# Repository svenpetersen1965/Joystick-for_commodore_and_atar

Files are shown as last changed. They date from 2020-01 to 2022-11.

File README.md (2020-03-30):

# Joystick-for_commodore_and_atar
This is a joystick for Commodore C64 etc.

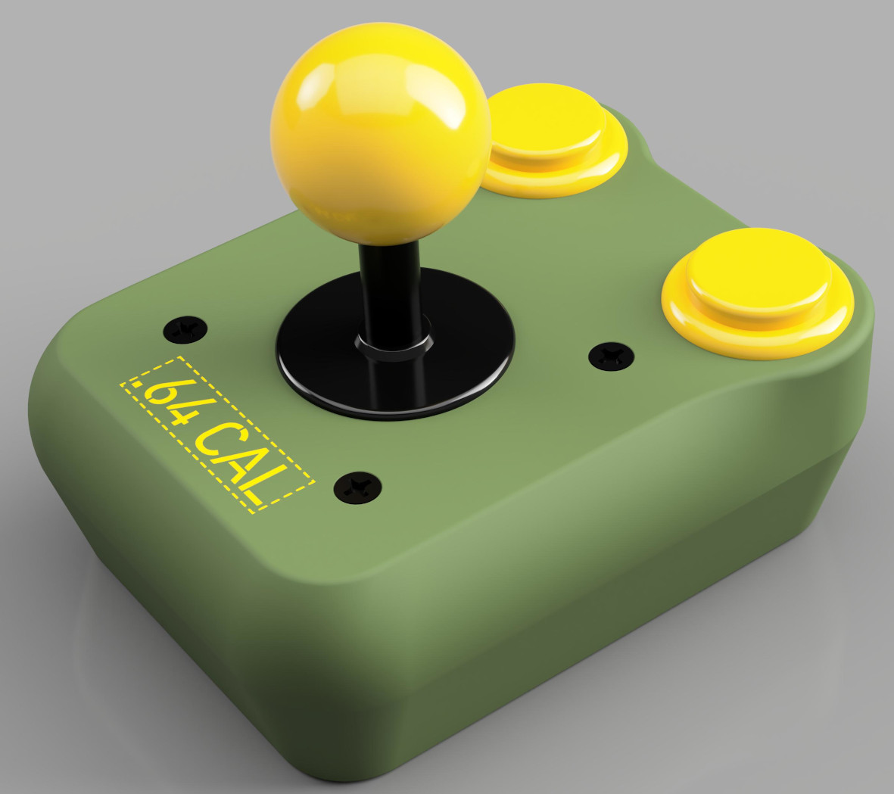
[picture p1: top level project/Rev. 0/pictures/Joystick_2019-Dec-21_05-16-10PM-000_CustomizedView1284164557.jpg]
Joystick


The Design is based on the widely available ZIPPYY joystick, which is of a  great quality.

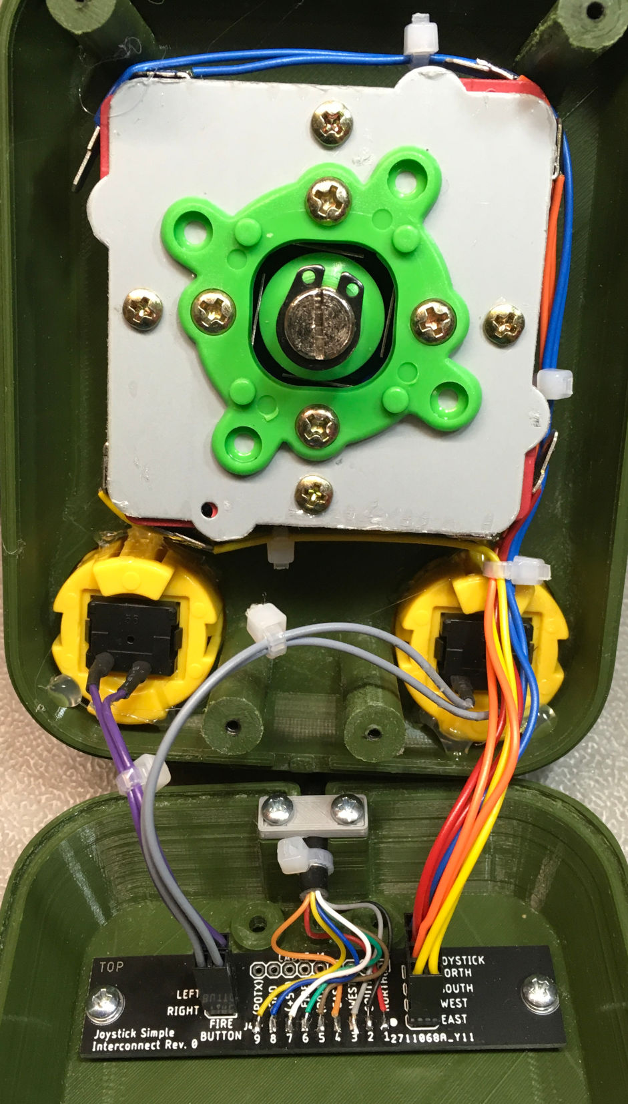
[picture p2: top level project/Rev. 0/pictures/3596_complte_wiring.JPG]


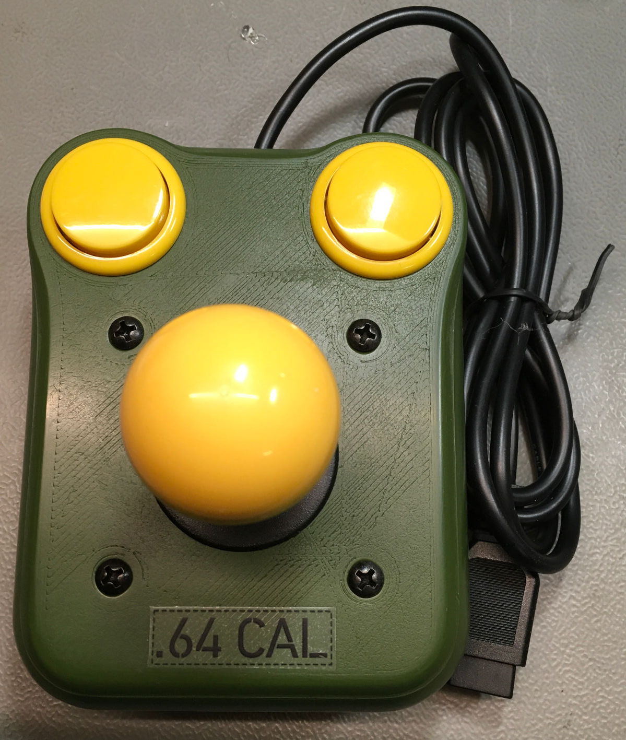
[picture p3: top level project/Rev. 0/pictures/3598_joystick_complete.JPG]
Joystick


There are now three alternative top shells:

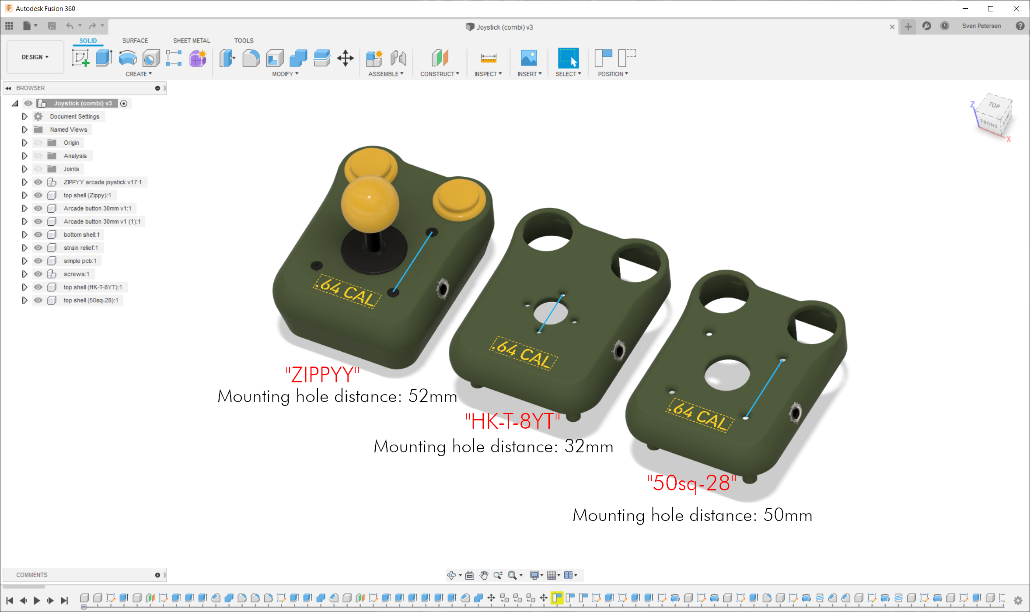
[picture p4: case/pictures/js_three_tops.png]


The original ZIPPYY top has a mounting hole distance of 52mm (square), the "HK-T-8YT" a distance of 32mm and the "50sq-28" a distance of 50mm (a ZIPPYY clone). The light blue lines show, how the distances were measured. 

Find some info on the required cable making <a href="http://tech.guitarsite.de/cable_making.html">on my website</a>

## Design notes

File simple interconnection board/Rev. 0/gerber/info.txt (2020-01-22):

      
       Board: js_simple
       Rev.:  0
  
       Files:
       ======
  
       All Gerber files are generated in extended gerber format (RS274X)
       *.TOP        : Film top copper
       *.BOT        :  -"- bottom copper
       *.STC        :  -"- top soldermask 
       *.STS        :  -"- bottom soldermask
       *.PLC        :  -"- silk screen top
       *.DK         : Drills plated Through (Excellon)
       *.NDK        : Drills not plated Through (Excellon)
       *.OUT        : Board outline

       Board Size:
       ===========
       Length     :   76.0 mm
       Width      :   16.0 mm
       Thickness  :   1.6 mm
       Material   :   FR 4
       Copper     :   35 um
       Surface    :   HASL
       
       Remarks:
       ========
       Width >= 12mil
       Distance >= 6mil
       Drill >= 0.4mm

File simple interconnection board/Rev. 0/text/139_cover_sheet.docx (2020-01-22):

Project Documentation

Joystick Simple Interconnect Board

Project number: 139

Revision: 0

Date: 22.12.2019

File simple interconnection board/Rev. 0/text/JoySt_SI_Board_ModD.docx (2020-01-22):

C64 Joystick – Simple Interconnect Board Rev. 0

Module description

# Introduction

This board serves as an interconnect module for the joystick. It provides separability of the arcade joystick, the fire buttons and the joystick cable and reduces the complexity of the wiring and the likelihood of failure.

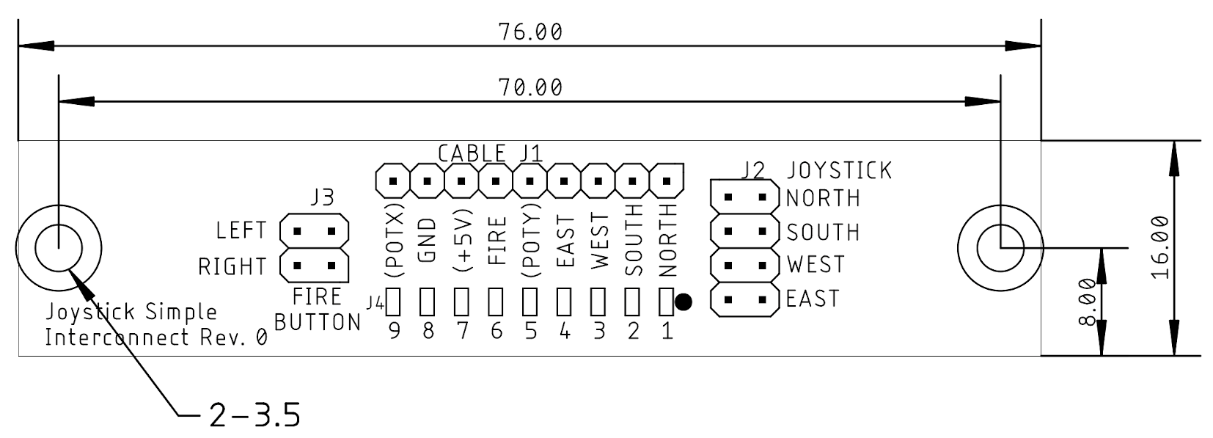
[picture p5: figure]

Figure 1: Measures of the PCB

# Connector Pinouts

## Cable connector – J1, J4

J1: Standard pin header, 9pin, 2.54mm pitch (optional)

J4: direct solder pads (surface)

Pin J1 | Pin J4 | Pin D-Sub (f) | Signal
1 | 1 | 1 | North
2 | 2 | 2 | South
3 | 3 | 3 | West
4 | 4 | 4 | East
5 | 5 | 5 | PotY*
6 | 6 | 6 | Fire
7 | 7 | 7 | +5V*
8 | 8 | 8 | GND
9 | 9 | 9 | PotX*

## Arcade joystick connector – J2

Standard pin header, 2x4 pins, 2.54mm pitch, matching connector: 2x4 DuPont crimp housing

Signal | Pin | Pin | Signal
North | 1 | 2 | GND
South | 3 | 4 | GND
West | 5 | 6 | GND
East | 7 | 8 | GND

## Fire Buttons – J3

Standard pin header, 2x2 pins, 2.54mm pitch, matching connector: 2x2 DuPont crimp housing

Signal | Pin | Pin | Signal
Right button | 1 | 2 | GND
Left button | 3 | 4 | GND

## Connecting the Board

The cable with the D-SUB can either be connected to J1 or J4, whatever is easier. The pads of J4 are connected to vias (that means, they have a drill which is plated through). This is to provide more stability to the pads, which would be easy to tear off without those via.

The arcade joystick is connected to J2 and it does not matter, which side of the micro switch is connected to GND or the direction signals (North, South etc.). They do not have a dedicated direction.

The same applies to the fire buttons. It also does not matter, which button is connected to “Left” and “Right”, because both buttons are parallel, the connect to the single Fire signal of the Joystick.

JoySt_SI_Board_ModD.docx 22.12.2019 12:29 Drafted by Sven Petersen Page 2 of 2 Doc.-No.: 139-6-01-00

JoySt_SI_Board_ModD.docx 22.12.2019 12:29 Drafted by Sven Petersen Page 1 of 1 Doc.-No.: 139-6-01-00

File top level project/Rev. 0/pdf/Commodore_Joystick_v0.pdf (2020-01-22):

# Project Documentation

## Commodore C64 - Joystick

## Project number: 141

## Revision: 0

## Date: 19.01.2020

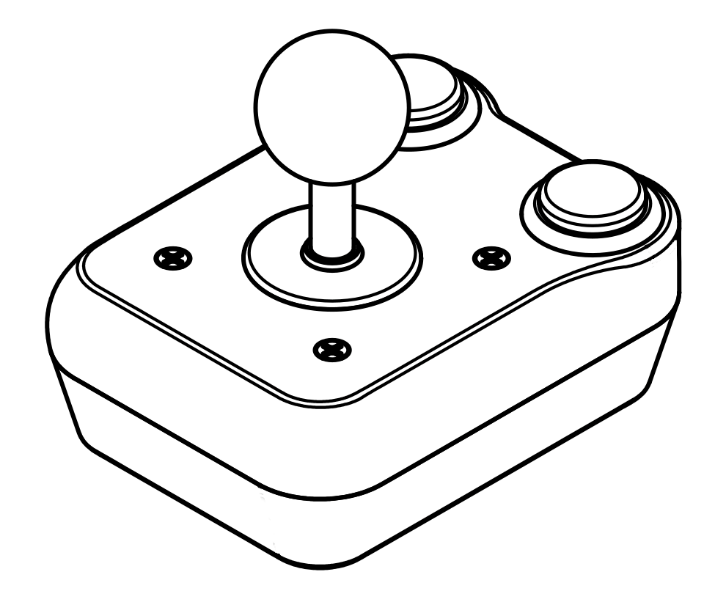
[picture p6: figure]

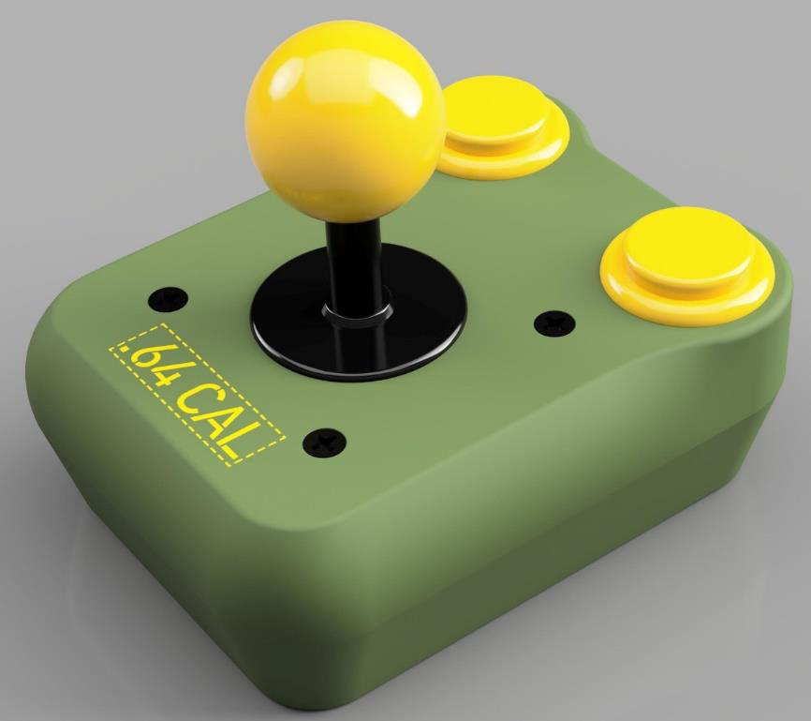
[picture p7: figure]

Joystick_TL_ModD.docx | | 22.01.2020 10:53
Drafted by Sven Petersen | Page 1 of 12 | Doc.-No.: 141-6-01-00

### Joystick for Commodore – Top Level Project Rev. 0

### Module description

Table of Content

## Introduction

This joystick is based on the ZIPPYY arcade joystick, 30mm arcade buttons, a prefabricated joystick cable, a PCB, some wires and a 3D printed enclosure.

Figure 1: Rendering of the Joystick (Fusion 360)

The ZIPPYY joystick was chosen for the microswitch mechanism with the levers, which seems to be an excellent concept. Other joysticks are a bit less expensive, but since the assembly work for a joystick and the printing time for the enclosure is the crucial factor, the increased material costs for a better quality might make sense.

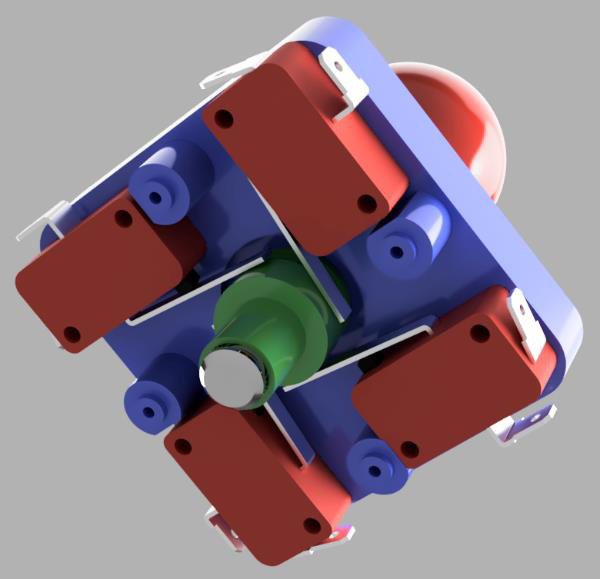
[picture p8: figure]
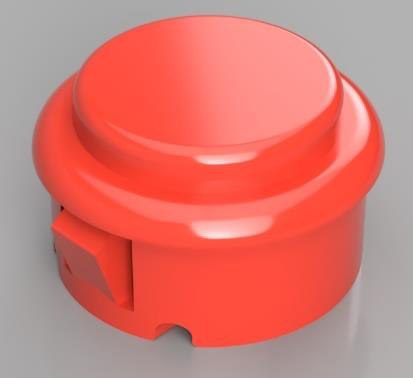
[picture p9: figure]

Drafted by Sven Petersen | Page 2 of 12 | Doc.-No.: 141-6-01-00

Figure 2: Microswitch mechanism of the ZIPPYY joystick (Fusion 360 rendering).

The interconnects of joysticks, buttons and the cable are accomplished with a PCB. This provides easier assembly and service and reduces the likelihood of failure. It makes the bottom half with the cable and the top half with the joystick and buttons separable.

## Components

The ZIPPYY joystick can be found on Ebay and AliExpress. The search terms are “ZIPPYY” or “ZIPPY” and the price varies a lot.

The Arcade buttons are 30mm arcade buttons and can be found on the same sales platforms.

Figure 3: 30mm arcade button (Fusion 360 rendering)

There are different types of 30mm arcade buttons, the type shown in Figure 3 fits into the case. Do
not use the “long type with screw mounts”. The enclosure fits perfectly with most types. Some have a
little bit shorter snap-in pin. Those buttons stay in the enclosure, but might require a drop of hot glue to stay flush.
The prefabricated cable is a “5.9ft 1.8M Controller Joystick Extension Cable for Sega Game Console
Systems“. The male 9 ways D-SUB connector of this extension cable is not required for the project (It is big, too) and can be cut off. The cable is available from Ebay and AliExpress.

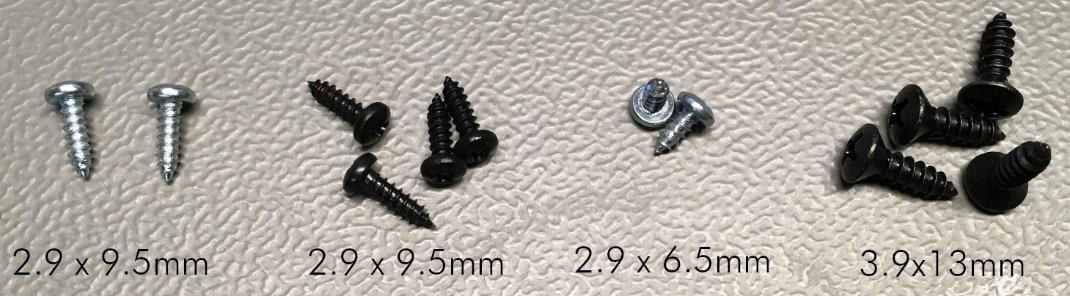
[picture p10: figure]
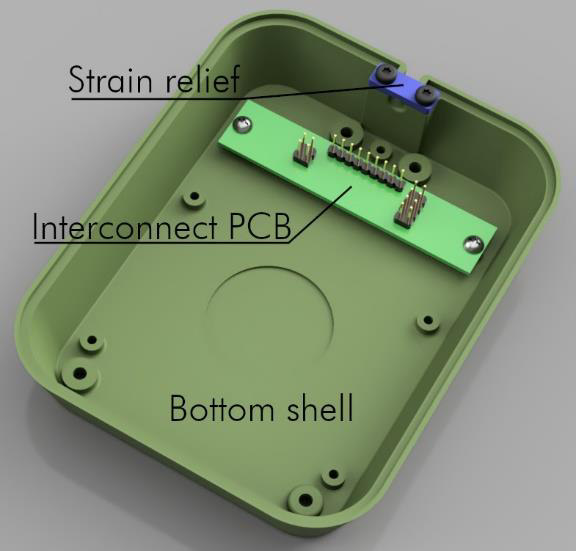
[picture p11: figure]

Drafted by Sven Petersen | Page 3 of 12 | Doc.-No.: 141-6-01-00

Figure 4: The screws which are used in the assembly

The case consists of three 3D printed parts: A top shell, a bottom shell and a strain relief. Two or three sorts of screws are required:

Pos. Qty Type | Purpose
1 | 2 | 2.9x9.5mm (DIN 7981, tapping screw) | Strain Relief
2 | 4 | 2.9x9.5mm (DIN 7981, tapping screw) | Top to bottom shell
3 | 2 | 2.9x6.5mm (DIN 7981, tapping screw) | PCB to bottom shell
4 | 4 | 3.9x13mm (DIN 7983, tapping screw, countersunk) | Joystick to top shell

A simple interconnect PCB serves for connecting the cable to the ZIPPYY joystick and the arcade buttons.

The countersunk tapping screws are part of the joystick, but it might be desired to have black finished screws. Pos. 1 and 2 are the same type, the screws for the bottom shell might also be wanted with a black finish.

Figure 5: Bottom shell assembly

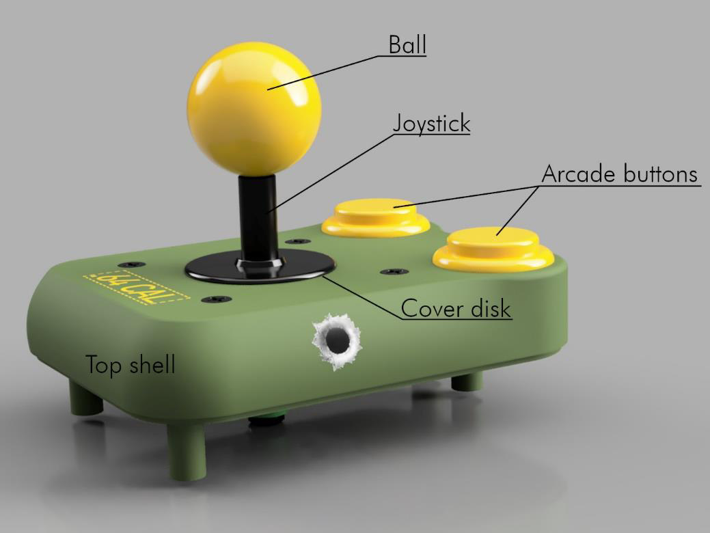
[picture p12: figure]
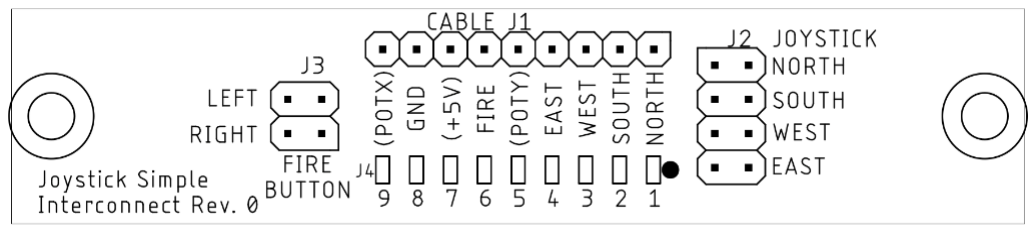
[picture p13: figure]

Drafted by Sven Petersen | Page 4 of 12 | Doc.-No.: 141-6-01-00

Figure 6: Top shell assembly

Figure 7: The PCB (Simple Interconnect)

## Wiring the Joystick

First, the PCB should be mounted in the bottom shell (2.9 x 6.5mm screws). The Male connector should be cut off the joystick cable, then the outer insulation should be stripped off (30mm). The single wires should be stripped off about 2mm, each. Then the cable can be installed with the strain relief. It is recommended to add a cable tie at the end of the outer insulation as an additional slip out protection.

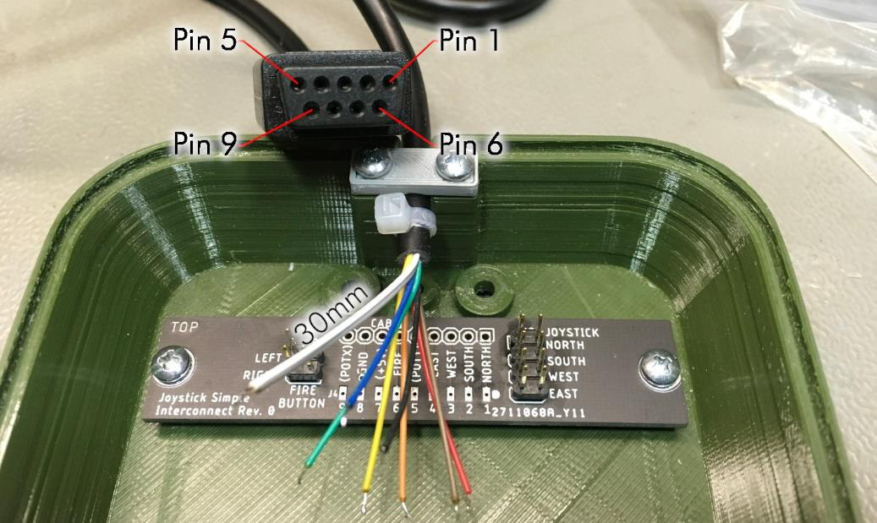
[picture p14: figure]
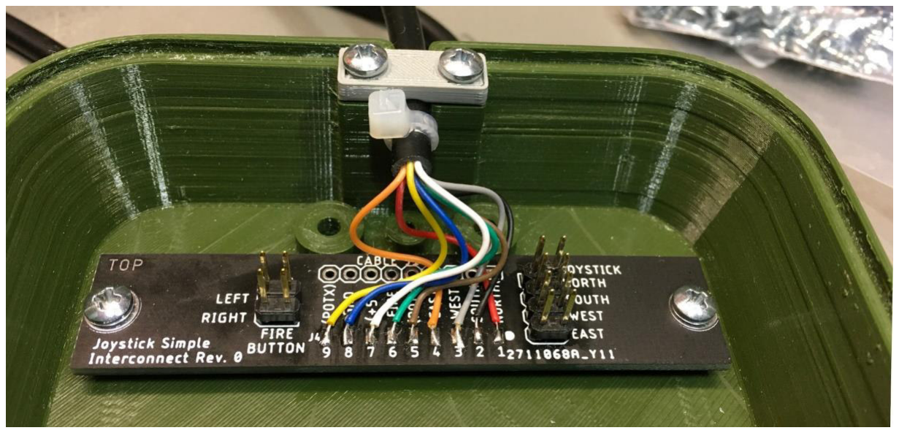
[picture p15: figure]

Drafted by Sven Petersen | Page 5 of 12 | Doc.-No.: 141-6-01-00

Figure 8: Installing the PCB and the joystick cable

It is not sure, that the wire colors are a standard for all available D-Sub extension cords. So, it is recommended to measure between the pins if the connector and the end of the wires. The numbering of the pins is shown in Figure 8.

The wires are directly soldered to the solder pads (J4) of the installed PCB. This is a comfortable and fast way, that reduces the likelihood of dry solder joints.

Figure 9: Soldered joystick cable

The colors of the particular joystick cable were colored like this:

Pad | Color | Function
1 | red | North/up
2 | black | South/down
3 | grey | West/left
4 | orange | East/right
5 | brown | PotY
6 | green | Fire
7 | white | +5V
8 | blue | GND
9 | yellow | PotX

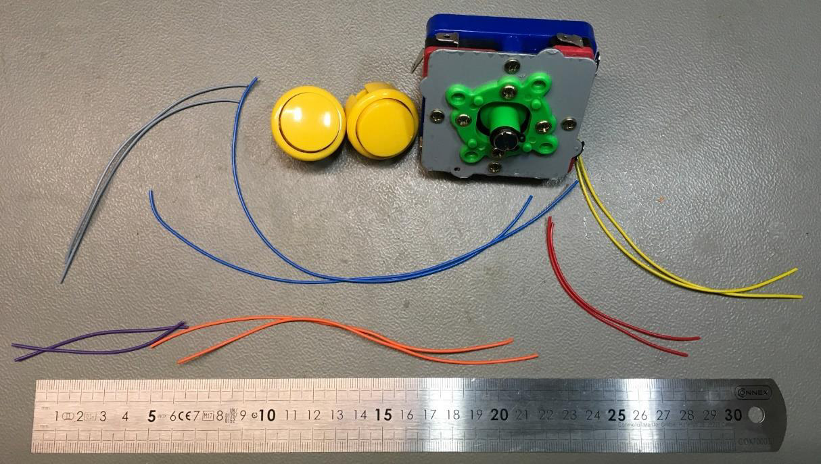
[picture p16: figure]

Drafted by Sven Petersen | Page 6 of 12 | Doc.-No.: 141-6-01-00

It should always be checked with the ohmmeter, that these colors are correct. Confusing the pins will at least result in an abnormal joystick behavior. In the worst case, the joystick can cause a short circuit between +5V and GND.

Figure 10: Wiring the joystick and the buttons

It is recommended to wire the joystick with differently colored wires (AWG24/0.25mm²). At least four colors are required top help not confusing the directions. The length can be cut in advance.

Direction | Color | Length
North | blue | 22cm
West | orange | 16cm
South | red | 9cm
East | yellow | 15cm
Right Button | grey | 12cm
Left Button | violet | 7cm

The colors are just a recommendation and depend on the available colors.

It is most comfortable to solder the wires onto the spade connectors of the joystick before it is mounted into the top shell.

For the buttons, shrinkable sleeves can be used (like shown in Figure 11), it is not necessary, though. Here, the directions are also shown.

The top plate of the ZIPPYY joystick is not required and can be removed by screwing off the ball, removing the cover disk and removing the four countersunk screws.

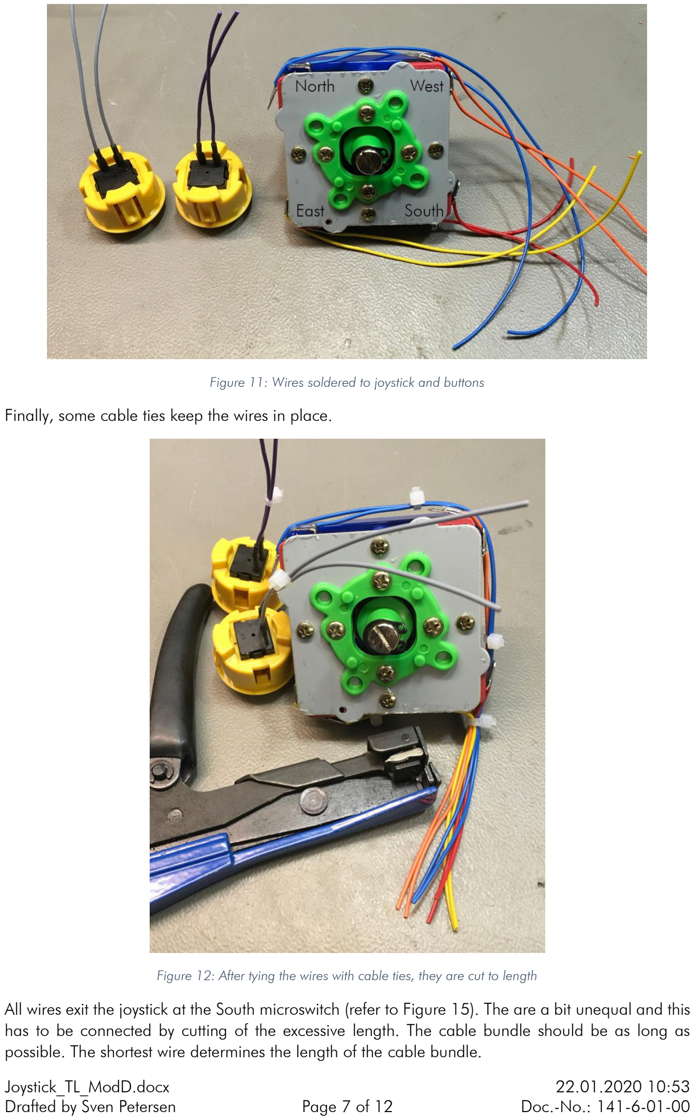
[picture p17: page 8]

Drafted by Sven Petersen | Page 7 of 12 | Doc.-No.: 141-6-01-00

Figure 11: Wires soldered to joystick and buttons

Finally, some cable ties keep the wires in place.

Figure 12: After tying the wires with cable ties, they are cut to length

All wires exit the joystick at the South microswitch (refer to Figure 15). The are a bit unequal and this has to be connected by cutting of the excessive length. The cable bundle should be as long as possible. The shortest wire determines the length of the cable bundle.

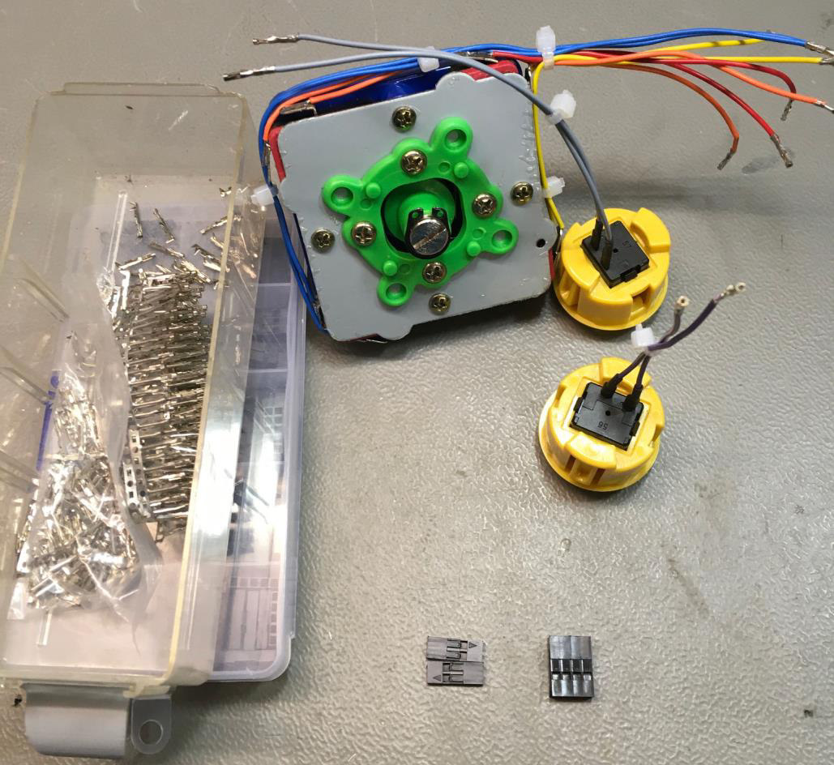
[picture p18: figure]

Drafted by Sven Petersen | Page 8 of 12 | Doc.-No.: 141-6-01-00

Crimping is a good and reliable method to attach connectors to single wires. The DuPont connectors are versatile and wide spread. The crimp tools are inexpensive. Engineer PA-09 or PA-20 are the recommended tools for this purpose.

Figure 13: Wires with Dupont crimp terminals

It is not recommended to attach the crimp terminals without suitable tools or to solder the wire stands to the terminals. They will probably not fit into the crimp housing.

In case soldering is preferred over crimping, some socket-strips are a half-decent solution. Another solution would be pre-fabricated DuPont (ribbon) cables (30cm) and the required crimp housings, since the single way crimp housings can be removed easily (slightly lift the holding tongue of the housing) and it is as easy to slide them into the required crimp housing. DuPont cables, terminals and housings are available from the sales platform, mentioned before. In this case, the work has to be done in an inversed sequence. The ribbon cable should stand out about 7-8cm at the “southern” corner of the joystick (Figure 14).then the single wire (pairs) should be separated from the ribbon cable only as far as required and soldered to the spade connectors of the joystick from South, then West, then North, then East on the other side. Cable ties might still be required, but I have not tried out, yet.

Figure 13 shows the joystick and the button wires with crimped Dupont terminals. The crimp housings are also shown here. For the arcade buttons a 1x2 way housing each is suggested, for the joystick a 4x2 housing is required.

It does not matter, which side of the micro switches (of the joystick) is connected to the direction signal and which side to ground.

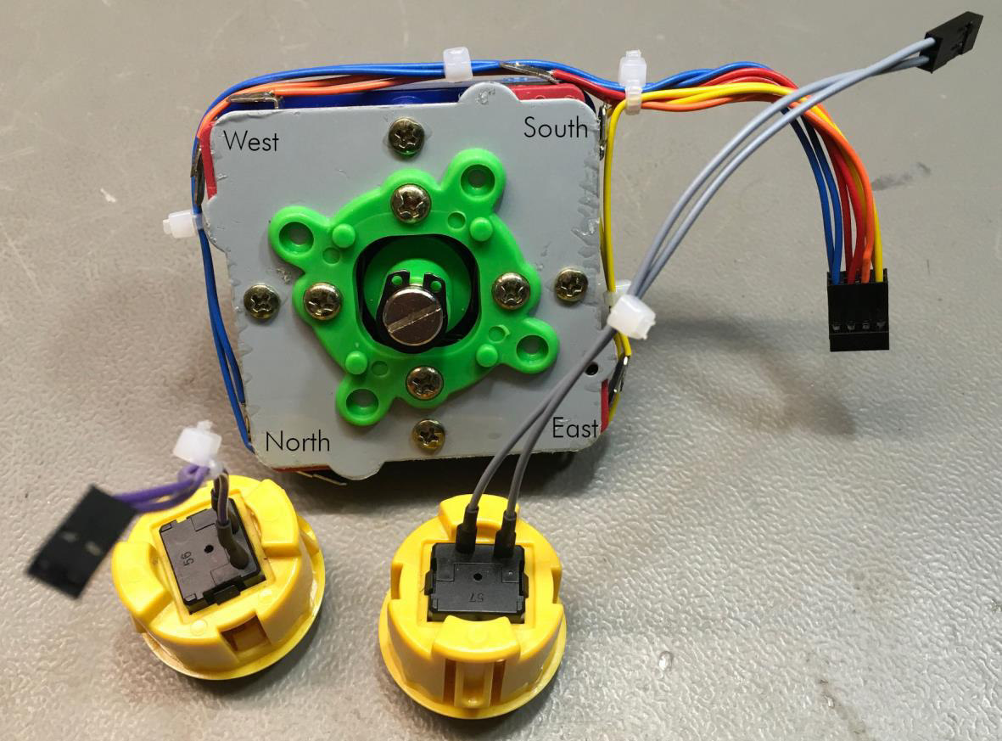
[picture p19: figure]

Drafted by Sven Petersen | Page 9 of 12 | Doc.-No.: 141-6-01-00
Color Signal Pin | Pin Signal Color
blue | North | 1 | 2 | GND | blue
red | South | 3 | 4 | GND | red
orange | West | 5 | 6 | GND | orange
yellow | East | 7 | 8 | GND | yellow

The joystick and buttons with crimp housings is shown in Figure 13.

Figure 14: Buttons and joystick with crimp housings

Now, the joystick and the buttons can be mounted into the top shell (Figure 15). The buttons should sit well in the mounting holes. In case they move to much due to a too short snap in pin, they can be secured with a small amount of hot glue. The joystick is screwed to the top shell with countersunk 3.9 x 13mm tapping screws (refer to Figure 4). If the look of the original joystick screws is desired, those can be used. The cover disk and the ball can be reattached now.

Finally, the top assembly can be connected to the bottom assembly. The orientation is shown on the PCB beside the connector for the joystick (J2). It should not be confused. In case of failure, the joystick will behave strange.

The connectors for the buttons have to be oriented from horizontally (see Figure 7, J3). Swapping connection for the left and right button has no effect on the functionality, since both are connected to the same (fire) signal. When connected vertically, the buttons will not have any effect.

A complete and correct wiring is shown in Figure 16.

The joystick can now be closed and screwed with four 2.9x9.5mm screws (see Figure 4). Four rubber feet should be attached to the bottom (Figure 17).

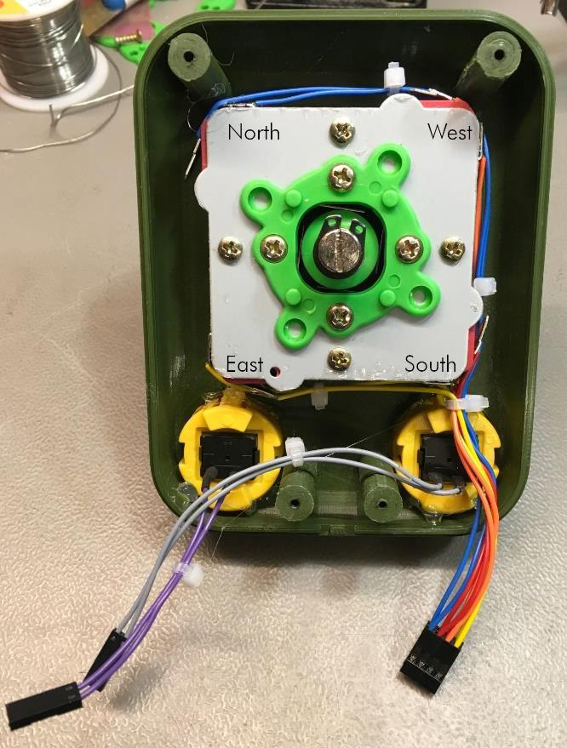
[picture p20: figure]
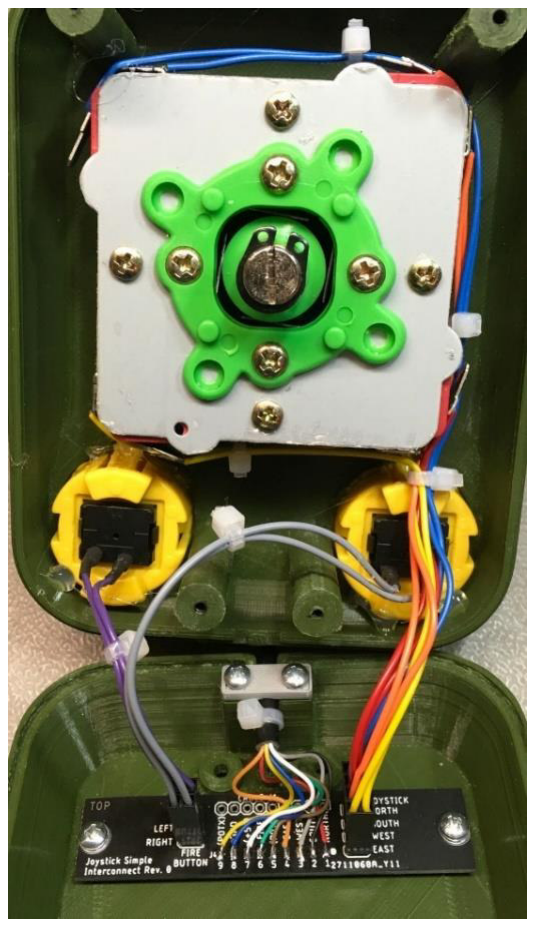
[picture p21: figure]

Drafted by Sven Petersen | Page 10 of 12 | Doc.-No.: 141-6-01-00

Figure 15: Top assembly

Figure 16: Complete wiring

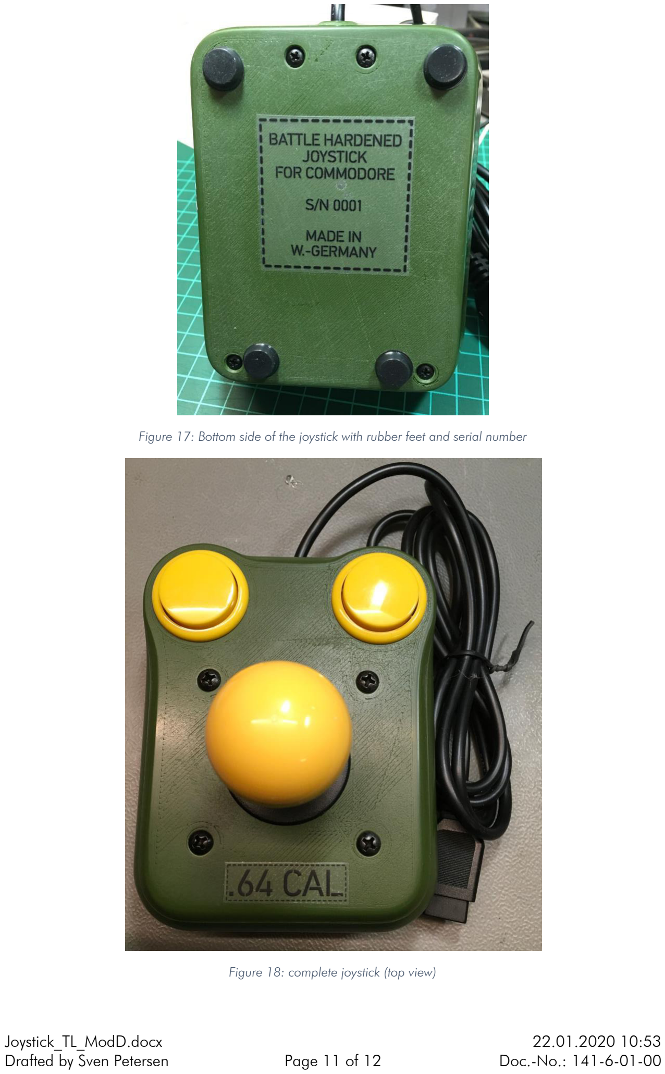
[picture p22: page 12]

Drafted by Sven Petersen | Page 11 of 12 | Doc.-No.: 141-6-01-00

Figure 17: Bottom side of the joystick with rubber feet and serial number

Figure 18: complete joystick (top view)

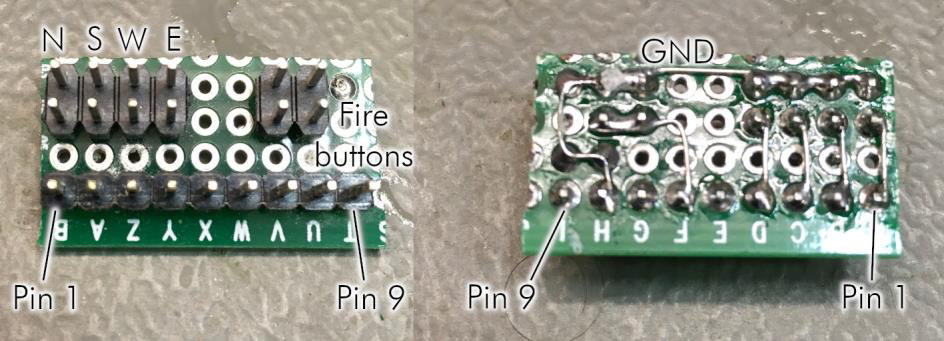
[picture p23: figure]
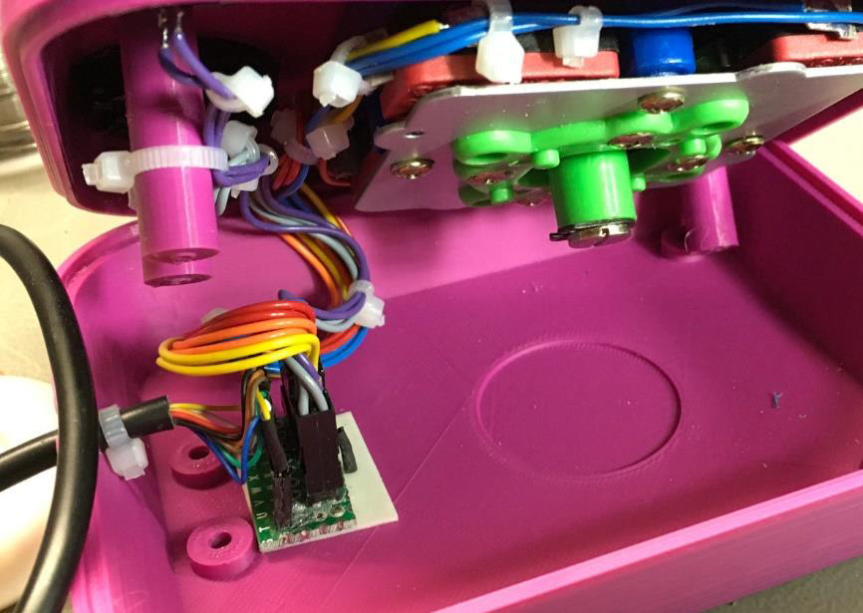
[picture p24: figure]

Drafted by Sven Petersen | Page 12 of 12 | Doc.-No.: 141-6-01-00

## Decals

The decals are fun, but not required for the function of the joystick. I have used laser printable, transparent sticker foil (HERMA 4375). Printing other than dark colors on the transparent sticker-foil is not recommended. Light colors require a light background.
The print for the labels can be found in the “inkscape” sub-directory of the “case” directory.

## Simple interconnect PCB

The PCB is very simple (and convenient). Wiring it on a perf board is not a big problem.

Figure 19: Interconnect on a perf board

The perf board could be attached to the bottom shell with a double-sided tape. A mirror tape is a good solution, that lasts very well.

Figure 20: Perf board inside the very first prototype

There are more screw posts inside the bottom shell. These are intended for future developments like an auto-fire board.

## Test

The test can be performed with a joystick test software for the C64, like the “Joytester II” (https://csdb.dk/release/?id=170175). Before, it should be made sure (ohmmeter) that the +5V is connected properly. If this would be connected to a button or the joystick, a closed contact would short +5V to ground, which would at least blow a fuse.

Pos. Qty Value Footprint Ref.-No. Comment

1 1 top shell 3D printed, PLA

2 1 bottom shel 3D printed, PLA

3 1 strain relief 3D printed, PLA

4 1 ZIPPY joystick see text (doc.-no. 141-6-01-00), page 2

5 2 arcade buttons 30mm see text (doc.-no. 141-6-01-00), page 2

6 1 prefabricated cable see text (doc.-no. 141-6-01-00), page 2

7 2 2.9x9.5mm tapping screw e.g DIN 7981

8 4 2.9x9.5mm tapping screw e.g DIN 7981 (black)

9 2 2.9x6.5mm tapping screw e.g DIN 7981

10 4 3.9x13mm, tapping, countersunk

screw

optional, e.g. DIN 7983 (black), see text (doc.-no. 141-6-01-00), page

3

11 1 PCB "Simple Interconnect board", Project No. 139, see text (doc.-no. 141-6-

01-00), page 4 and page 12

12 7 cable ties small

13 44cm blue, AWG24/0.25mm² wire, see text (doc.-no. 141-6-01-00), page 6
14 32cm orange, AWG24/0.25mm² wire, see text (doc.-no. 141-6-01-00), page 6

15 18cm red, AWG24/0.25mm² wire, see text (doc.-no. 141-6-01-00), page 6

16 30cm yellow, AWG24/0.25mm² wire, see text (doc.-no. 141-6-01-00), page 6
17 24cm grey, AWG24/0.25mm² wire, see text (doc.-no. 141-6-01-00), page 6
18 14cm violet, AWG24/0.25mm² wire, see text (doc.-no. 141-6-01-00), page 6

19 12 DuPont crimp terminals see text (doc.-no. 141-6-01-00), page 8

20 2 2x1 way DuPont crimp housing see text (doc.-no. 141-6-01-00), page 8

21 1 2x4 way DuPont crimp housing see text (doc.-no. 141-6-01-00), page 8

### 22 labels transparent sticker foil, see text (doc.-no. 141-6-01-00), page 12

## Commodore Joystick Rev. 0

## Bill of Material Rev. 0.0

Joystick_BOM_v0_0.xlsx

Drafted by Sven Petersen Page 1 of 1

22.01.2020 10:55
Doc.No.: 141-5-01-00.0

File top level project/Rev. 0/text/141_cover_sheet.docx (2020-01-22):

Project Documentation

Commodore C64 - Joystick

Project number: 141

Revision: 0

Date: 19.01.2020


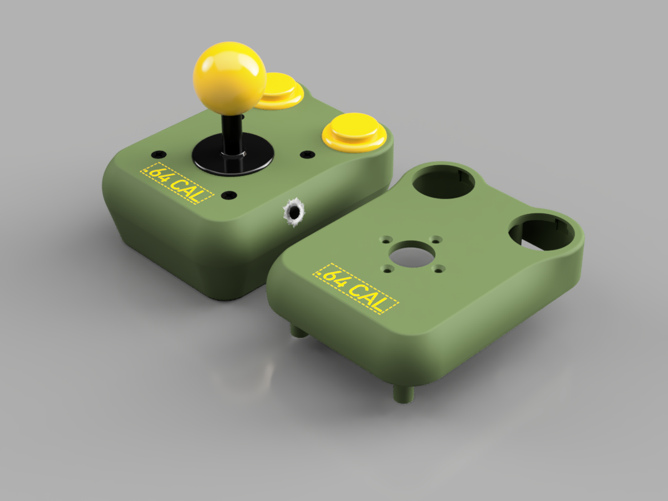
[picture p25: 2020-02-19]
case/pictures/Joystick_2020-Feb-13_11-32-09AM-000_CustomizedView11592183182.png

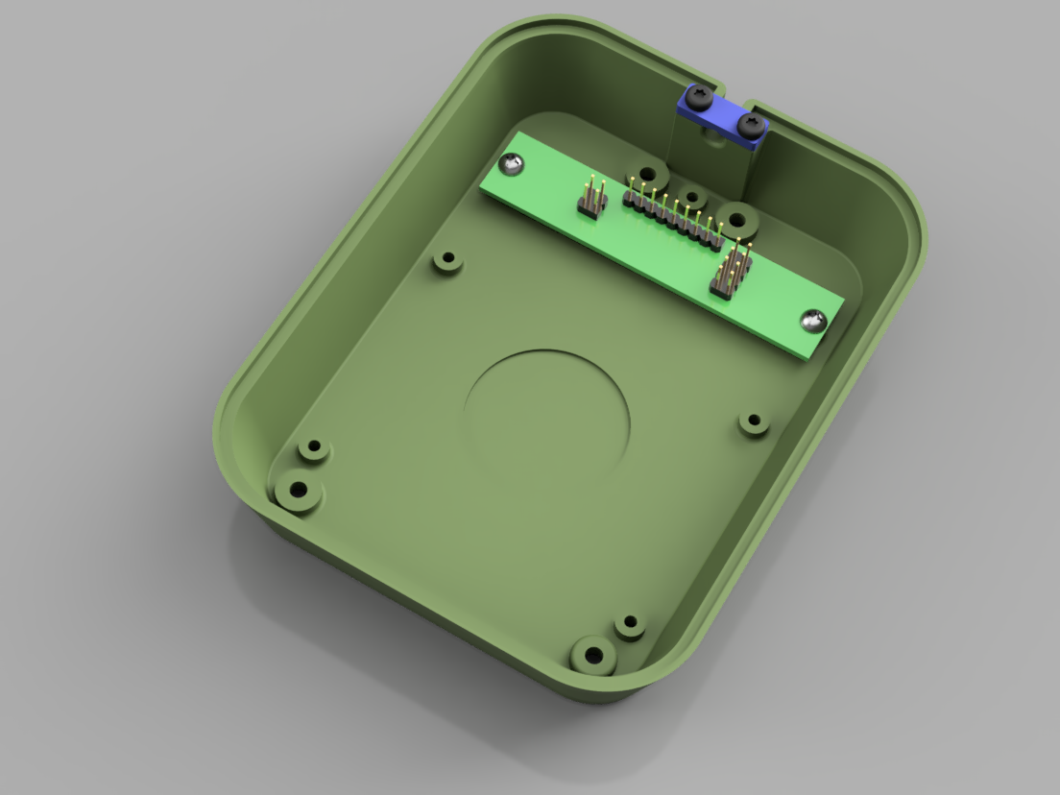
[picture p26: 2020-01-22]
top level project/Rev. 0/pictures/Joystick_2020-Jan-20_01-36-59PM-000_CustomizedView3770380408.png

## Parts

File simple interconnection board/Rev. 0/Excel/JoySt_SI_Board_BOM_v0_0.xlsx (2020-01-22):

Joystick - Simple Interconnect Board Rev. 0
Bill of Material Rev. 0.0
Pos. | Qty | Value | Footprint | Ref.-No. | Comment
1 | 1 | 139-2-01-00 | 2 Layer | PCB Rev. 0 | 2 layer, Cu 35µ, HASL, 76.0 x 16.0mm, 1.6mm FR4
2 | 1 | 1x9, pitch 2.54mm | 1X09 | J1 | standard pin header
3 | 1 | 2x2, pitch 2.54mm | 2X02 | J3 | standard pin header
4 | 1 | 2x2, pitch 2.54mm | 2X04 | J2 | standard pin header

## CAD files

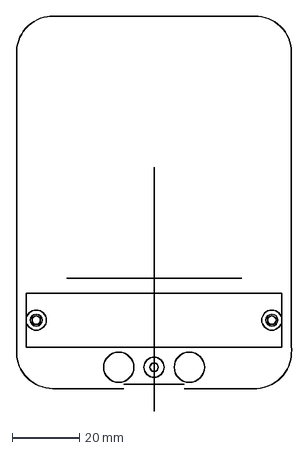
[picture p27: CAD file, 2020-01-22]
case/dxf/simple_pcb.dxf
81.7 x 117.4 mm

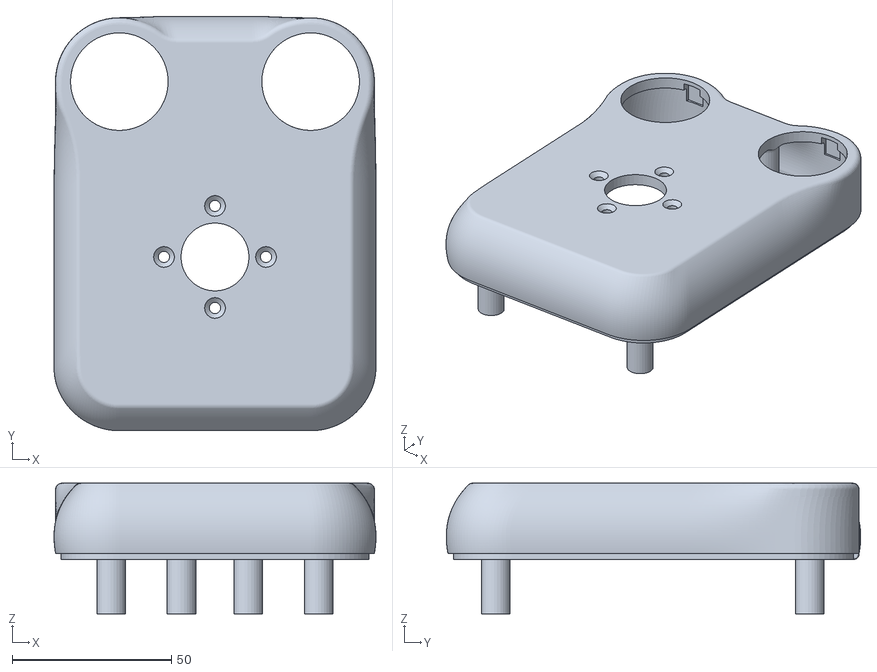
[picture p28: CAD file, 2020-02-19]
case/stl/js_top_shell_(HK-T-8YT).stl
101.0 x 130.0 x 41.0

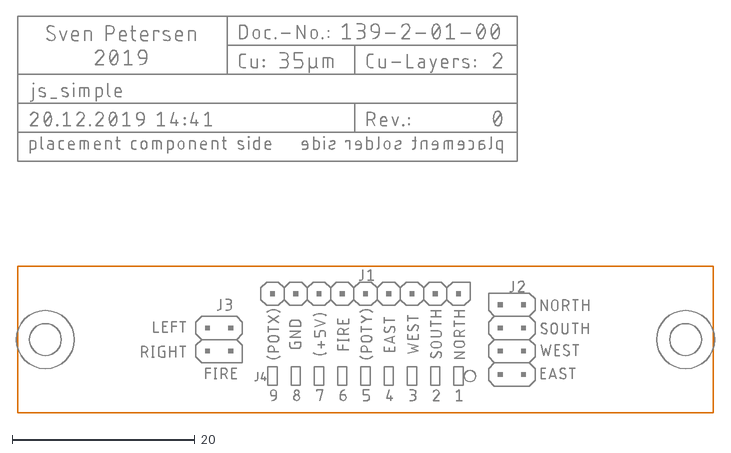
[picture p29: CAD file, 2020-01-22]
simple interconnection board/Rev. 0/dxf/js_simple.dxf
76.4 x 43.3

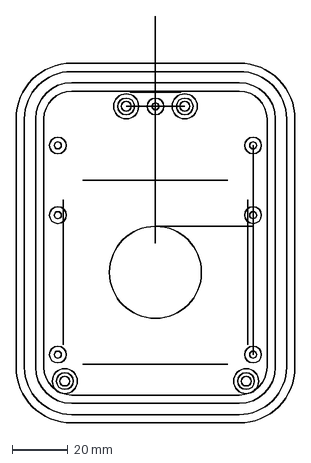
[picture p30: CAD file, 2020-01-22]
case/dxf/bottom shell bottom level.dxf
100.0 x 145.9 mm

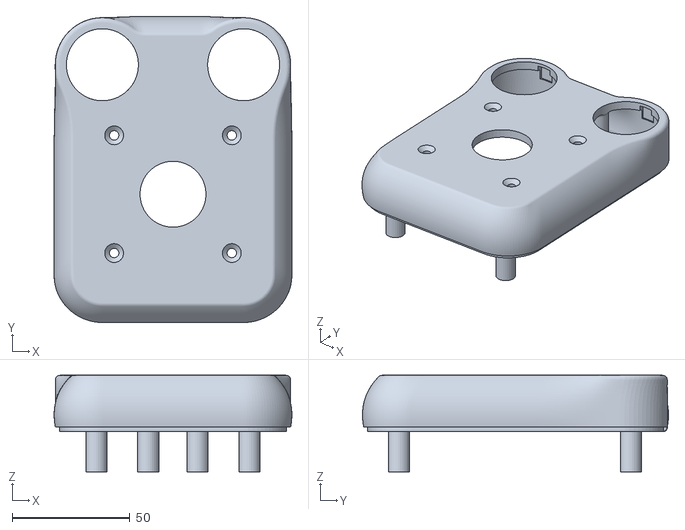
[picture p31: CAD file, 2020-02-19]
case/stl/js_top_shell_(50sq-28).stl
101.0 x 130.0 x 41.0

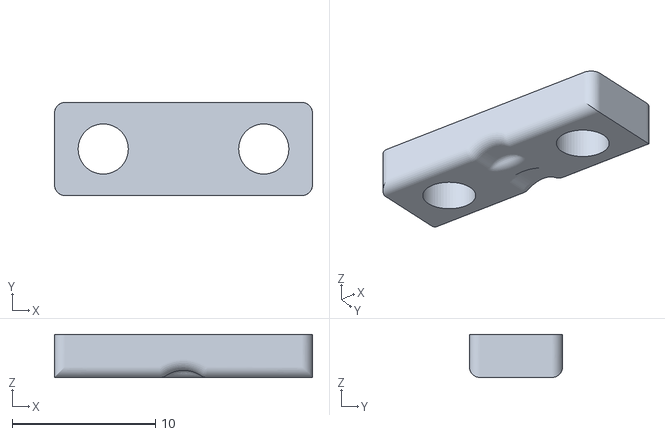
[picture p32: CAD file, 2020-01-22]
case/stl/js_strain_relief.stl
18.0 x 6.50 x 3.00

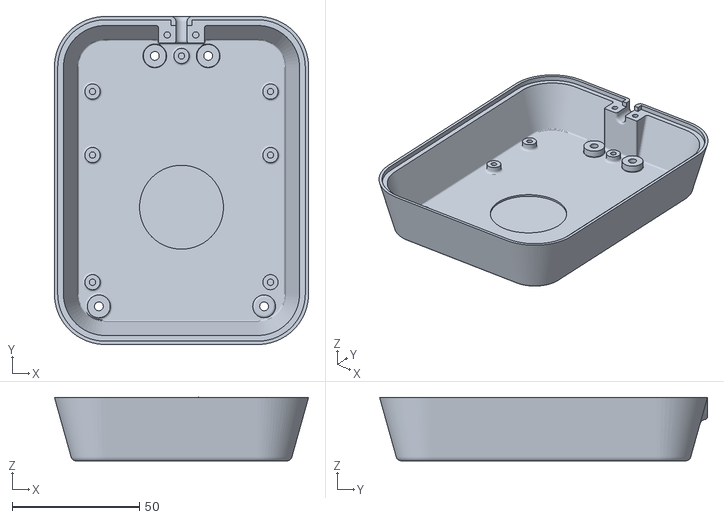
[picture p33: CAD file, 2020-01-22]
case/stl/js_bottom_shell.stl
100.0 x 129.0 x 25.0

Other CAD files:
case/stl/js_top_shell.stl

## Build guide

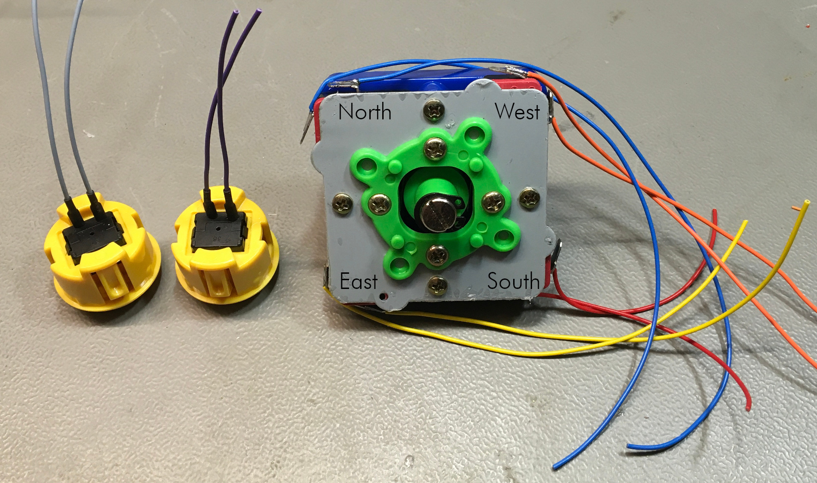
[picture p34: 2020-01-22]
top level project/Rev. 0/pictures/3591_top_wiring_02.JPG

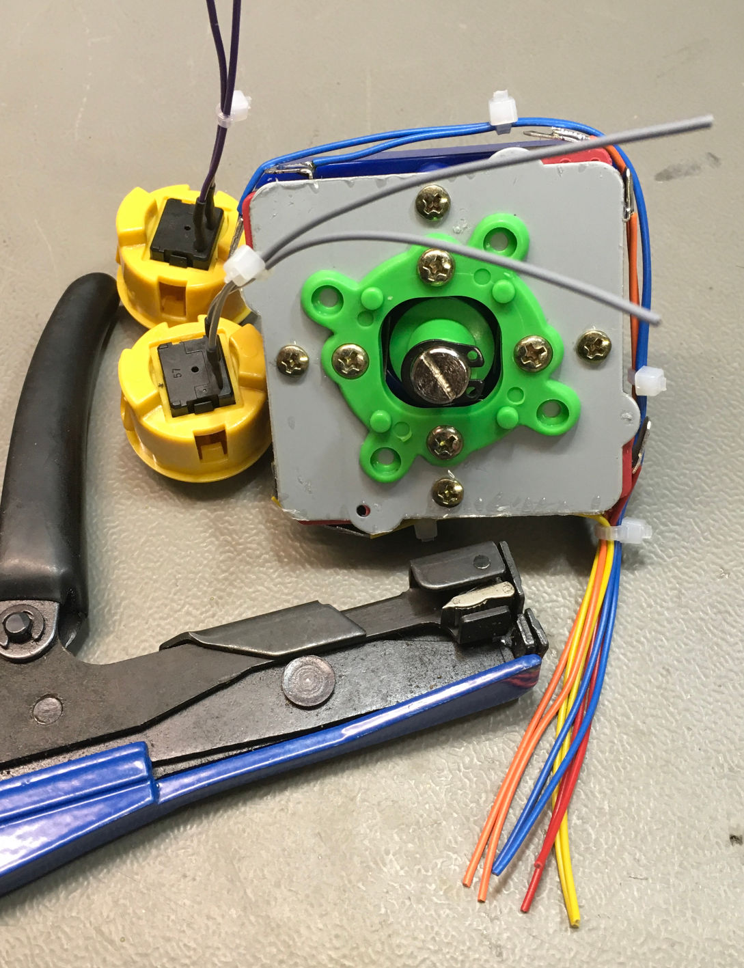
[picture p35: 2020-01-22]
top level project/Rev. 0/pictures/3592_top_wiring_03.JPG

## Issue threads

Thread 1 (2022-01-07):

Version with resistors for arduino

mistepien, 2022-01-07:
Hello,

great project. Could you be so nice and add version with resistors for arduino?

220 Ohm | 1 | Up
220 Ohm | 2 | Down
220 Ohm | 3 | Left
220 Ohm | 4 | Right
220 Ohm | 5 | Pot Y
220 Ohm | 6 | Fire
(n/c) | - | 7 | +5V
GND | - | 8 | GND
 220 Ohm | 9 | Pot X

It would be very nice to have ability to make C64 joystick running with arduino board. Such board would great interface between arduino and C64.

svenpetersen1965, 2022-01-07:
In which way should the resistors be added? To ground, to VCC or series? I need this a bit more detailed to consider it.

mistepien, 2022-01-07:
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

I thought about sth like that. Above the goldpins J2 next row of goldpins. Each pin in new upper row would be separated by place for resistor. Except 5V and GND. Arduino would be connectec through the upper row. If someone does not need arduno the lower goldpin row will be good for him and he will not solder resistors.

In addition please connect POTX, POTY and 5V to J4 respective soldering spots.

BTW, great idea. Just solder all cables from db9 cable and utilize it in civilized way. So simple and genius as well. Thanks!

svenpetersen1965, 2022-01-07:
Potx/y are not connnected anways. Why does the Arduino require the 220Ω in series? Do you know that? Is it a protection, in case the pin direction is accidentally set to output?

mistepien, 2022-01-07:
https://giters.com/doj/Ultimate-USB-to-Controlport

the is a passage about resistors between arduino and control port.

mistepien, 2022-01-07:
and why POTX and POTY are disconnected?

svenpetersen1965, 2022-01-07:
Because the joystick only has 4 direction bits and fire. No analog outputs.

svenpetersen1965, 2022-01-07:
And I had a look at your link. The project is about connecting a USB joystick to an arduino, which then mimics a vintage joystick at the control port. And you want to use my board as a carrier for the resistors. Well, a perf board will do that job as well. So please forgive me, when I close this issue and don’t change my board.
Regards,
Sven

Closed 2022-01-07.

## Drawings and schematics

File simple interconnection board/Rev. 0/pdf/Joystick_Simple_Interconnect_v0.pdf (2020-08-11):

# Project Documentation

## Joystick Simple Interconnect Board

## Project number: 139

## Revision: 0

## Date: 22.12.2019

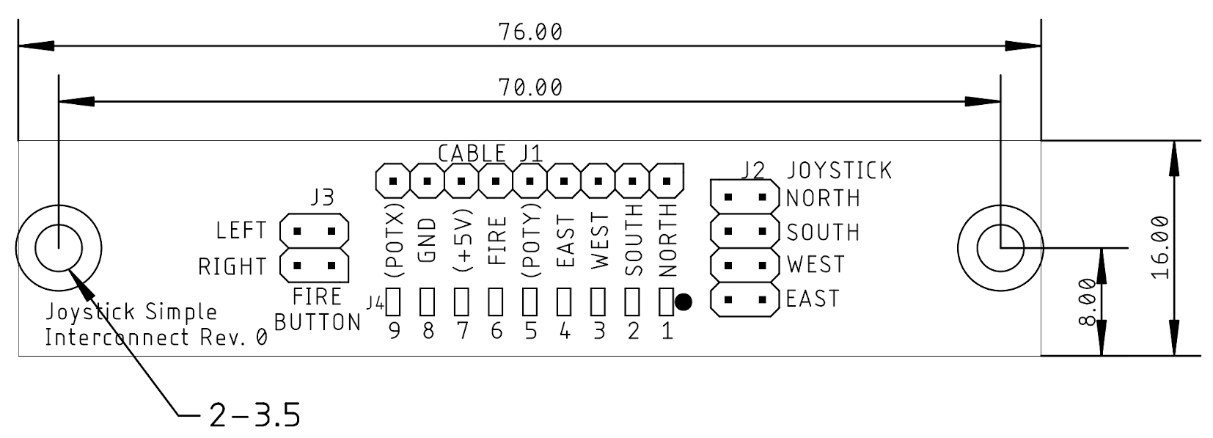
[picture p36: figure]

JoySt_SI_Board_ModD.docx | | 22.12.2019 12:29
Drafted by Sven Petersen | Page 1 of 2 | Doc.-No.: 139-6-01-00

### C64 Joystick – Simple Interconnect Board Rev. 0

### Module description

## Introduction

This board serves as an interconnect module for the joystick. It provides separability of the arcade joystick, the fire buttons and the joystick cable and reduces the complexity of the wiring and the likelihood of failure.

Figure 1: Measures of the PCB

## Connector Pinouts

### Cable connector – J1, J4

J1: Standard pin header, 9pin, 2.54mm pitch (optional)

J4: direct solder pads (surface)

Pin J1 | Pin J4 | Pin D-Sub (f) | Signal
1 | 1 | 1 | North
2 | 2 | 2 | South
3 | 3 | 3 | West
4 | 4 | 4 | East
5 | 5 | 5 | PotY*
6 | 6 | 6 | Fire
7 | 7 | 7 | +5V*
8 | 8 | 8 | GND
9 | 9 | 9 | PotX*

### Arcade joystick connector – J2

Standard pin header, 2x4 pins, 2.54mm pitch, matching connector: 2x4 DuPont crimp housing

Signal Pin | Pin Signal
North | 1 | 2 | GND
South | 3 | 4 | GND
West | 5 | 6 | GND
East | 7 | 8 | GND

JoySt_SI_Board_ModD.docx | | 22.12.2019 12:29
Drafted by Sven Petersen | Page 2 of 2 | Doc.-No.: 139-6-01-00

### Fire Buttons – J3

Standard pin header, 2x2 pins, 2.54mm pitch, matching connector: 2x2 DuPont crimp housing

Signal Pin | Pin Signal
Right button | 1 | 2 | GND
Left button | 3 | 4 | GND

### Connecting the Board

The cable with the D-SUB can either be connected to J1 or J4, whatever is easier. The pads of J4 are connected to vias (that means, they have a drill which is plated through). This is to provide more stability to the pads, which would be easy to tear off without those via.

The arcade joystick is connected to J2 and it does not matter, which side of the micro switch is connected to GND or the direction signals (North, South etc.). They do not have a dedicated direction.

The same applies to the fire buttons. It also does not matter, which button is connected to “Left” and “Right”, because both buttons are parallel, the connect to the single Fire signal of the Joystick.

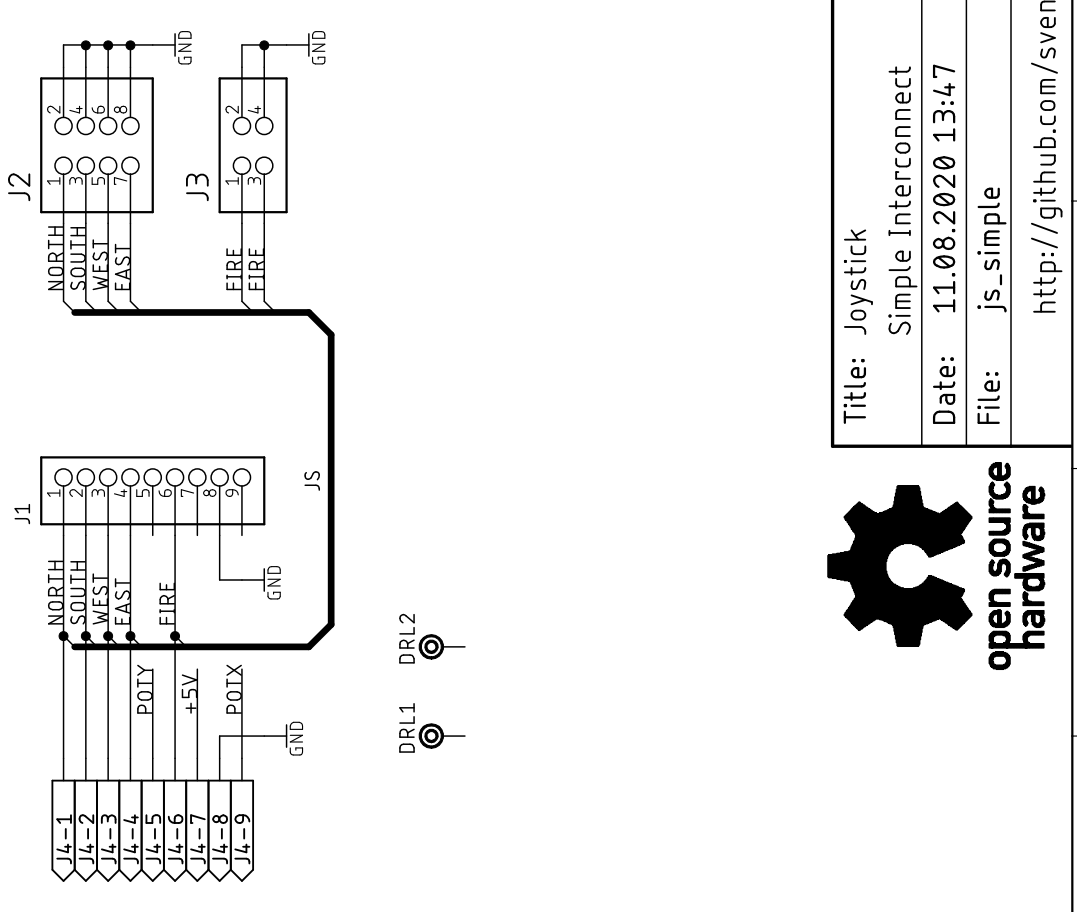
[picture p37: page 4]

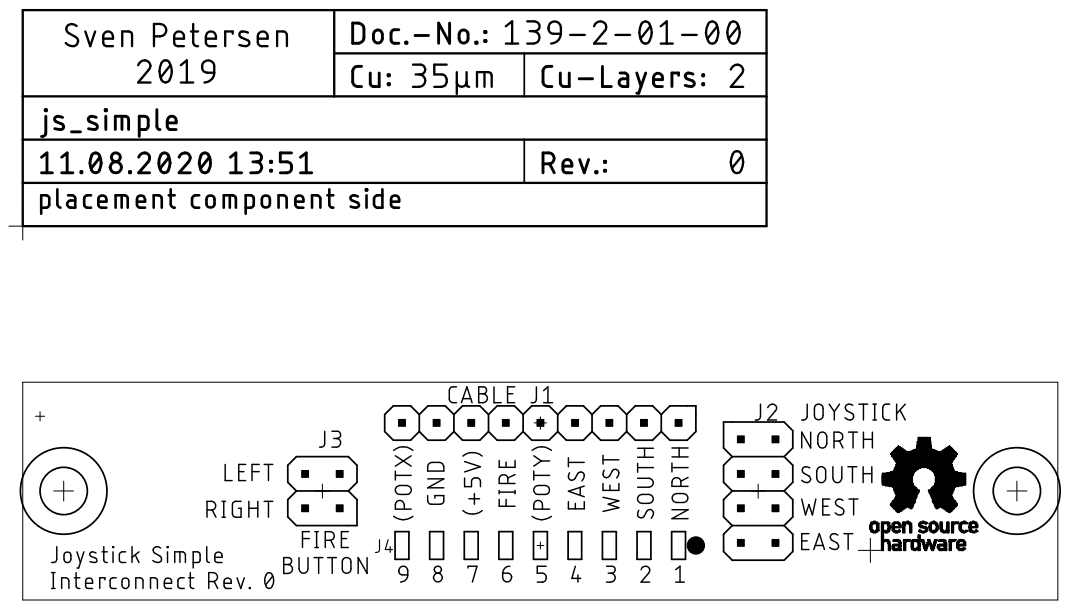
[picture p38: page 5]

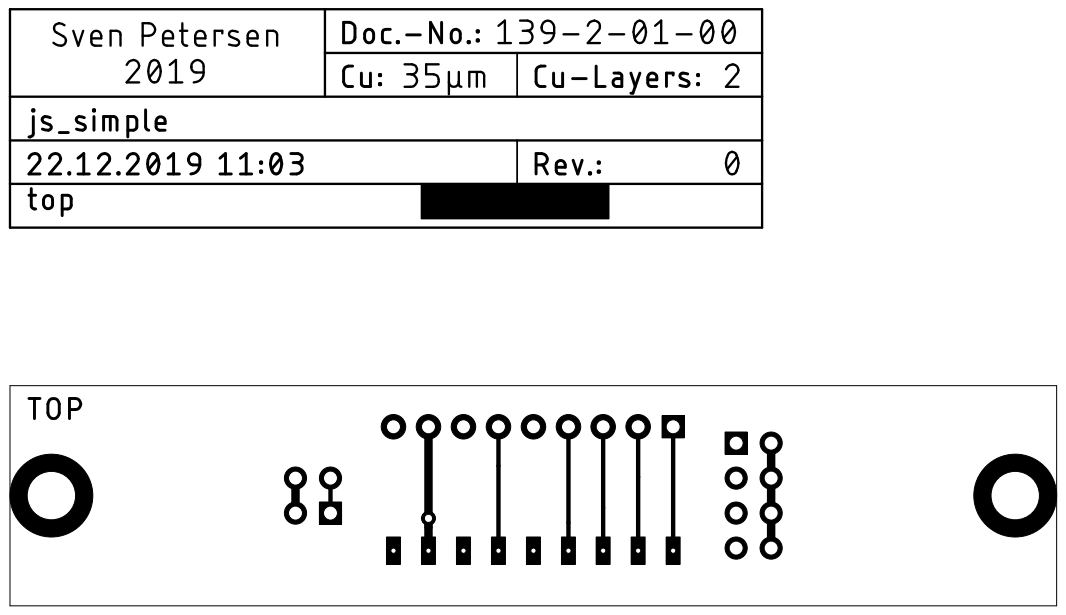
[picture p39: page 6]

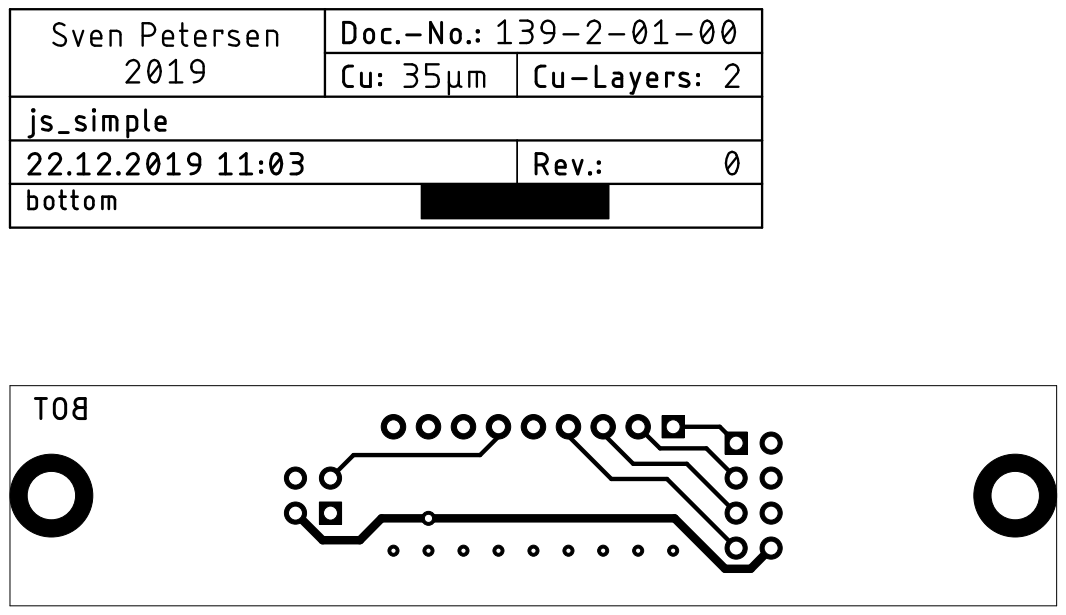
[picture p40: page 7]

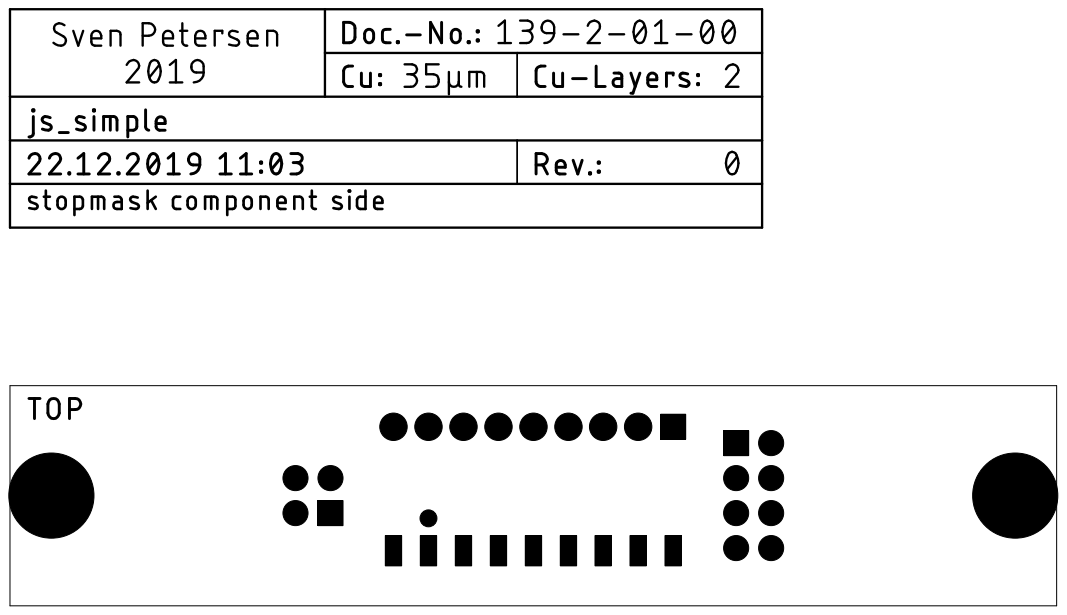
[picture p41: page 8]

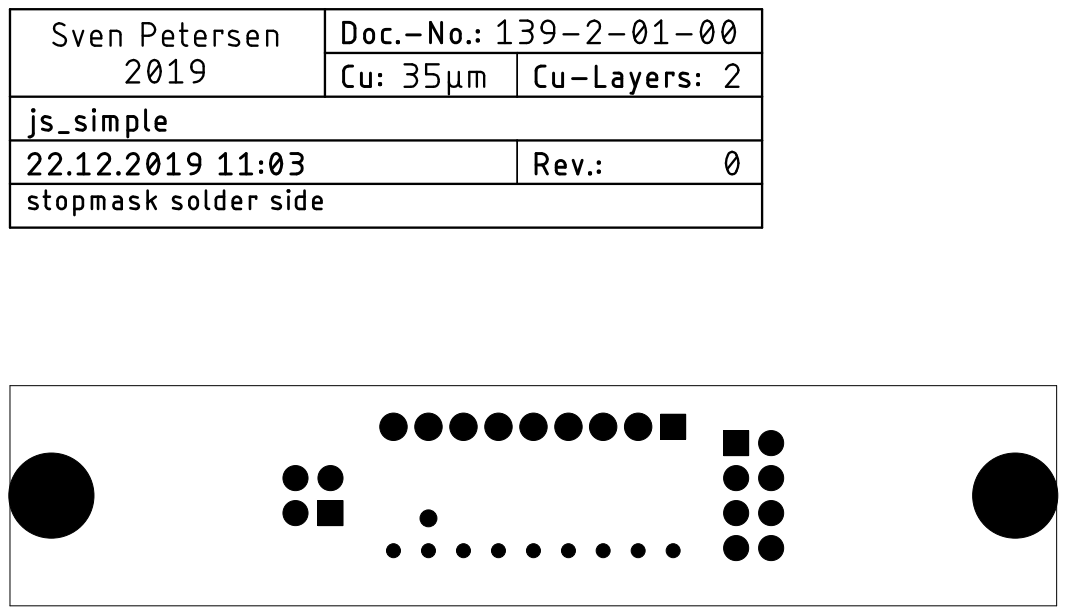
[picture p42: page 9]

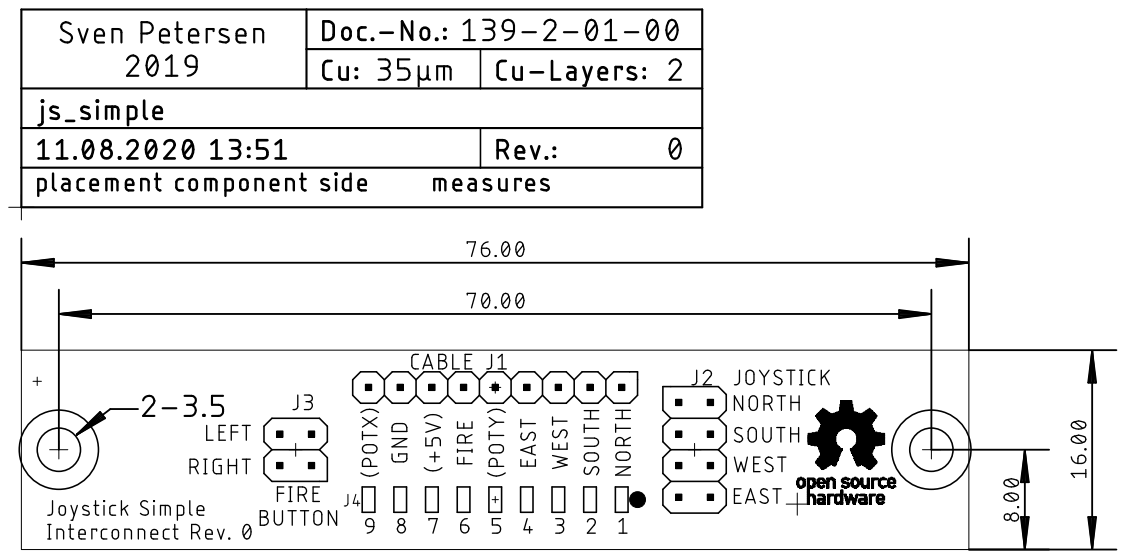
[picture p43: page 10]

Pos. Qty Value Footprint Ref.-No. Comment

1 1 139-2-01-00 2 Layer PCB Rev. 0 2 layer, Cu 35µ, HASL, 76.0 x 16.0mm, 1.6mm FR4

2 1 1x9, pitch 2.54mm 1X09 J1 standard pin header

3 1 2x2, pitch 2.54mm 2X02 J3 standard pin header

4 1 2x2, pitch 2.54mm 2X04 J2 standard pin header

## Joystick - Simple Interconnect Board Rev. 0

## Bill of Material Rev. 0.0

JoySt_SI_Board_BOM_v0_0.xlsx

Drafted by Sven Petersen Page 1 of 1

22.12.2019 12:39
Doc.No.: 139-5-01-00.0

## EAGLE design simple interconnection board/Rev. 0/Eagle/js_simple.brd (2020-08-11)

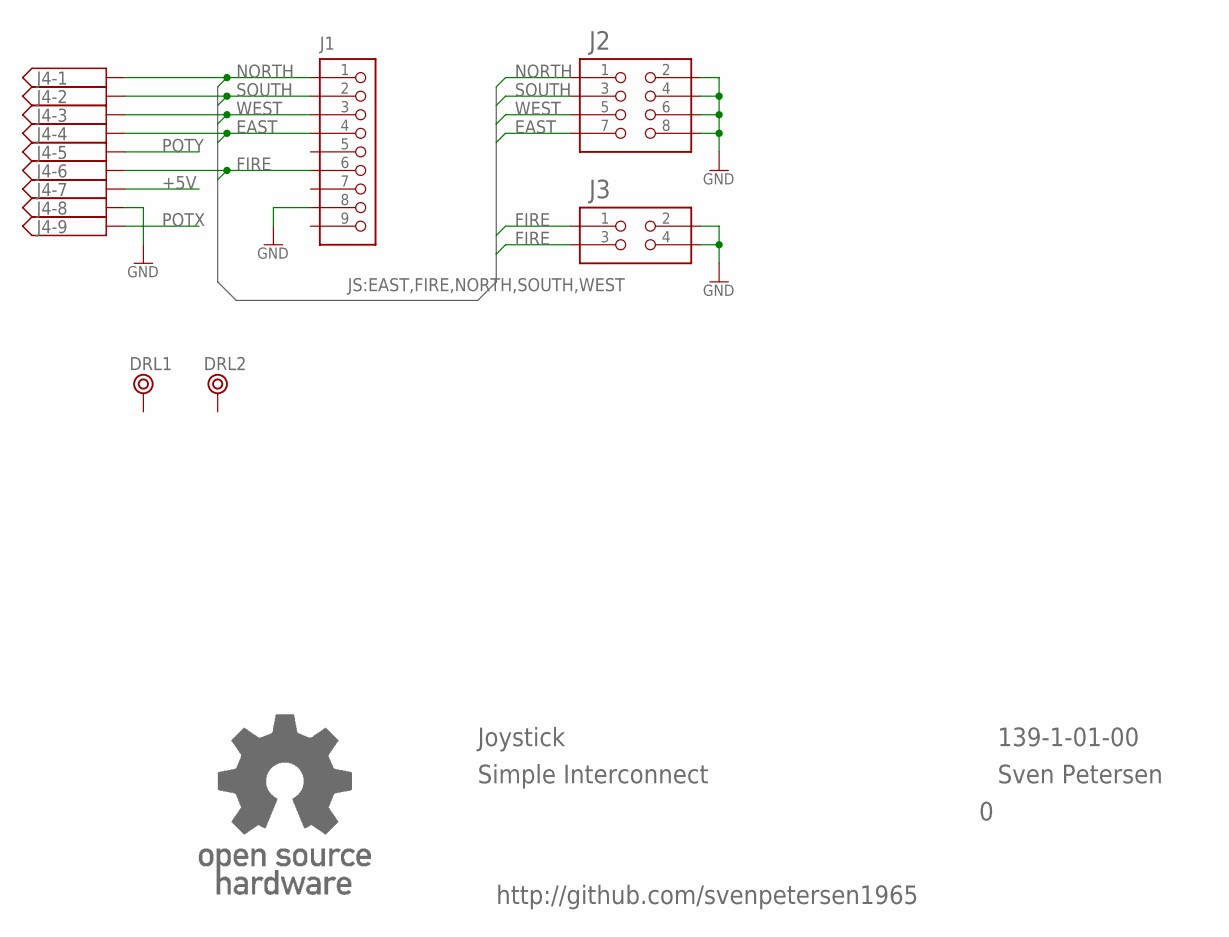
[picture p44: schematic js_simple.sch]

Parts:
DRL1, DRL2: BOHR3,5
J1: PINHD-1X9; 1X09
J2: PINHD-2X4; 2X04
J3: PINHD-2X2; 2X02
J4: 9X1X2SMD; 9PIN_1X2SMD
U$8: OPEN_SOURCE_HW; OPENHW

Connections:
+5V: J4.7
EAST: J1.4, J2.7, J4.4
FIRE: J1.6, J3.1, J3.3, J4.6
GND: J1.8, J2.2, J2.4, J2.6, J2.8, J3.2, J3.4, J4.8
NORTH: J1.1, J2.1, J4.1
POTX: J4.9
POTY: J4.5
SOUTH: J1.2, J2.3, J4.2
WEST: J1.3, J2.5, J4.3

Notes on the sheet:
Joystick
Simple Interconnect
139-1-01-00
Sven Petersen
http://github.com/svenpetersen1965

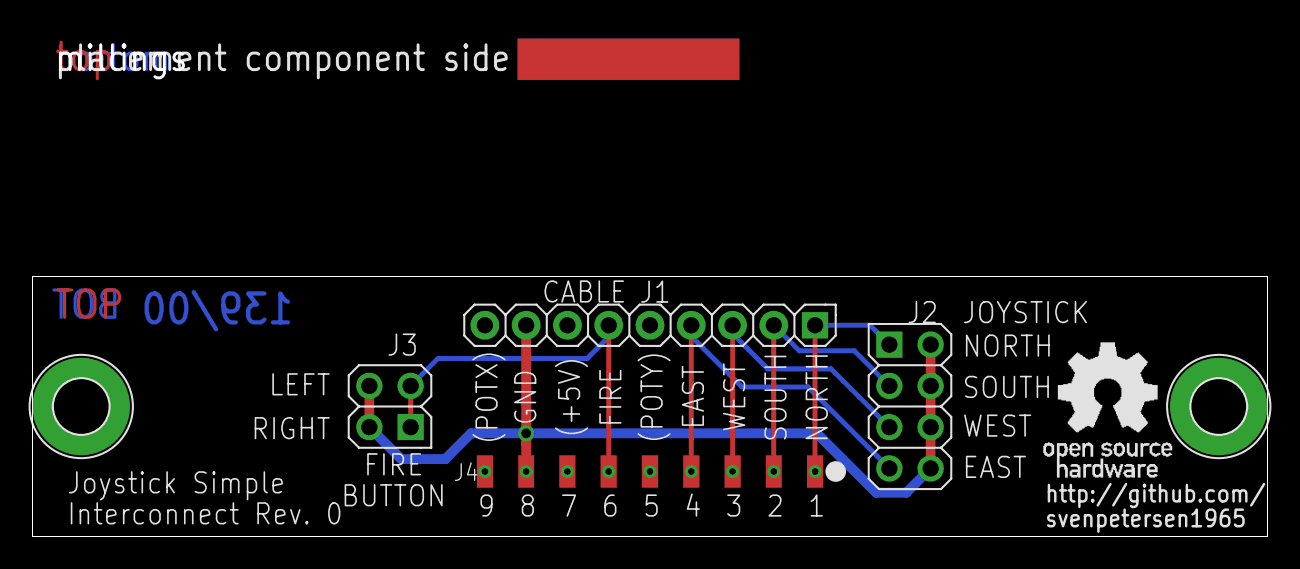
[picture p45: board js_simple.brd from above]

Board: 2 copper layers, 76.0 x 16.0 mm, 9 parts (0 on the bottom side), 6 nets.

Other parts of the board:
U$6: PCB-TITLE/
U$7: 2LAYER

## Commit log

2020-01-22 Initial upload
    [JoySt_SI_Board_BOM_v0_0.xlsx, Joystick v15.f3d, Joystick_BOM_v0_0.xlsx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]
2020-02-19 Two new top shells for different joystick types
    [js_top_shell_(50sq-28).stl, js_top_shell_(HK-T-8YT).stl]
2020-02-19 Delete Joystick v15.f3d
    Obsolete
    [Joystick v15.f3d]
2020-08-11 Silk Screen Update
    [js_simple.brd, js_simple.sch]
